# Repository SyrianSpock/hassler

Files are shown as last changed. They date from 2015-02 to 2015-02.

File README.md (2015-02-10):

Portable Hassler circuit
========================

Portable version of the hassler circuit to get rid of office noise.

This project focuses on building a portable version of the Hassler circuit.
Inspired by the analog pioneer Bob Widlar and the work of Craig at [analog zoo](http://www.analogzoo.com/2015/01/building-the-widlar-hassler).

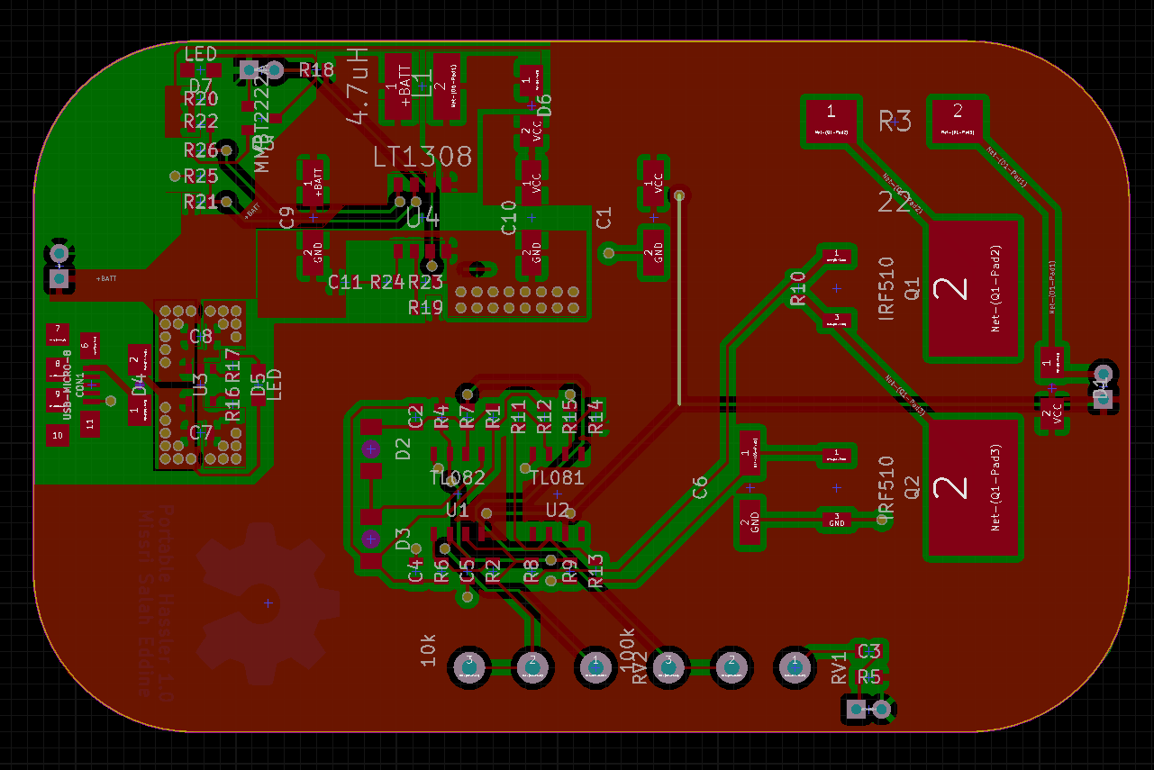
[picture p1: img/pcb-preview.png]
pcb


Features:
---------
* Emits a high frequency sound when there is noise
* Runs on one LiPo / Lithium-ion cell battery
* Micro USB rechargeable

License
-------
This project is released under the Creative Commons CC-BY-SA-4.0 license.
See http://creativecommons.org/licenses/by-sa/4.0/ for details.

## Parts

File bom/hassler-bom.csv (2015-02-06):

Reference | Value | Quantity | Kicad Footprint | URL
C1 | 220u | 1 | Capacitors_SMD:c_elec_6.3x7.7
C2 | 10p | 1 | SMD_Packages:SMD-0603
C3 | 1u | 1 | SMD_Packages:SMD-0603
C4 | 10u | 1 | SMD_Packages:SMD-0603
C5 | 680p | 1 | SMD_Packages:SMD-0603
C6 C9 C10 | 47u | 3 | Capacitors_SMD:c_elec_6.3x7.7
C7 C8 | 4.7u | 2 | SMD_Packages:SMD-0603
C11 | 330p | 1 | SMD_Packages:SMD-0603
CON1 | USB-MICRO-B | 1 | _connectors:_Micro-USB-AB-receptacle-SMT
D1 | S1J-13-F | 1 | Diodes_SMD:Diode-SMA_Standard
D2 D3 | 1N4148W | 2 | Diodes_SMD:Diode-MiniMELF_Standard
D4 D6 | MBRA140 | 2 | Diodes_SMD:Diode-SMA_Standard
D5 D7 | LED | 2 | LEDs:LED-0805
J1 | JST | 1 | _connectors:_Pin2mm_2
L1 | 4.7uH | 1 | _standard:Inductor2300
MIC1 | MICROPHONE | 1 | _connectors:_Pin2mm_2
Q1 Q2 | IRF510 | 2 | _standard:TO-263
Q3 | MMBT2222A | 1 | SMD_Packages:SOT-23
R1 R10 | 10M | 2 | SMD_Packages:SMD-0603
R2 R6 R12 | 1M | 3 | SMD_Packages:SMD-0603
R3 | 22 | 1 | _standard:PowerRes_SM_3
R4 R9 R15 R18 | 10k | 4 | SMD_Packages:SMD-0603
R5 | 22k | 1 | SMD_Packages:SMD-0603
R7 R8 R26 | 1k | 3 | SMD_Packages:SMD-0603
R11 | 20M | 1 | SMD_Packages:SMD-0603
R13 R14 | 2.2k | 2 | SMD_Packages:SMD-0603
R16 | 2k | 1 | SMD_Packages:SMD-0603
R17 | 330 | 1 | SMD_Packages:SMD-0603
R19 | 720k | 1 | SMD_Packages:SMD-0603
R20 | 470 | 1 | SMD_Packages:SMD-0603
R21 | 1.5M | 1 | SMD_Packages:SMD-0603
R22 R23 R25 | 100k | 3 | SMD_Packages:SMD-0603
R24 | 47k | 1 | SMD_Packages:SMD-0603
RV1 | 100k | 1 | Potentiometers:Potentiometer_WirePads_largePads
RV2 | 10k | 1 | Potentiometers:Potentiometer_WirePads_largePads
SP1 | SPEAKER | 1 | _connectors:_Pin2mm_2
SW1 | Off Switcher | 1 | _connectors:_Pin2mm_2
U1 | TL082 | 1 | SMD_Packages:SOIC-8-N
U2 | TL081 | 1 | SMD_Packages:SOIC-8-N
U3 | MCP73831 | 1 | SMD_Packages:SOT-23-5
U4 | LT1308 | 1 | _standard:S8

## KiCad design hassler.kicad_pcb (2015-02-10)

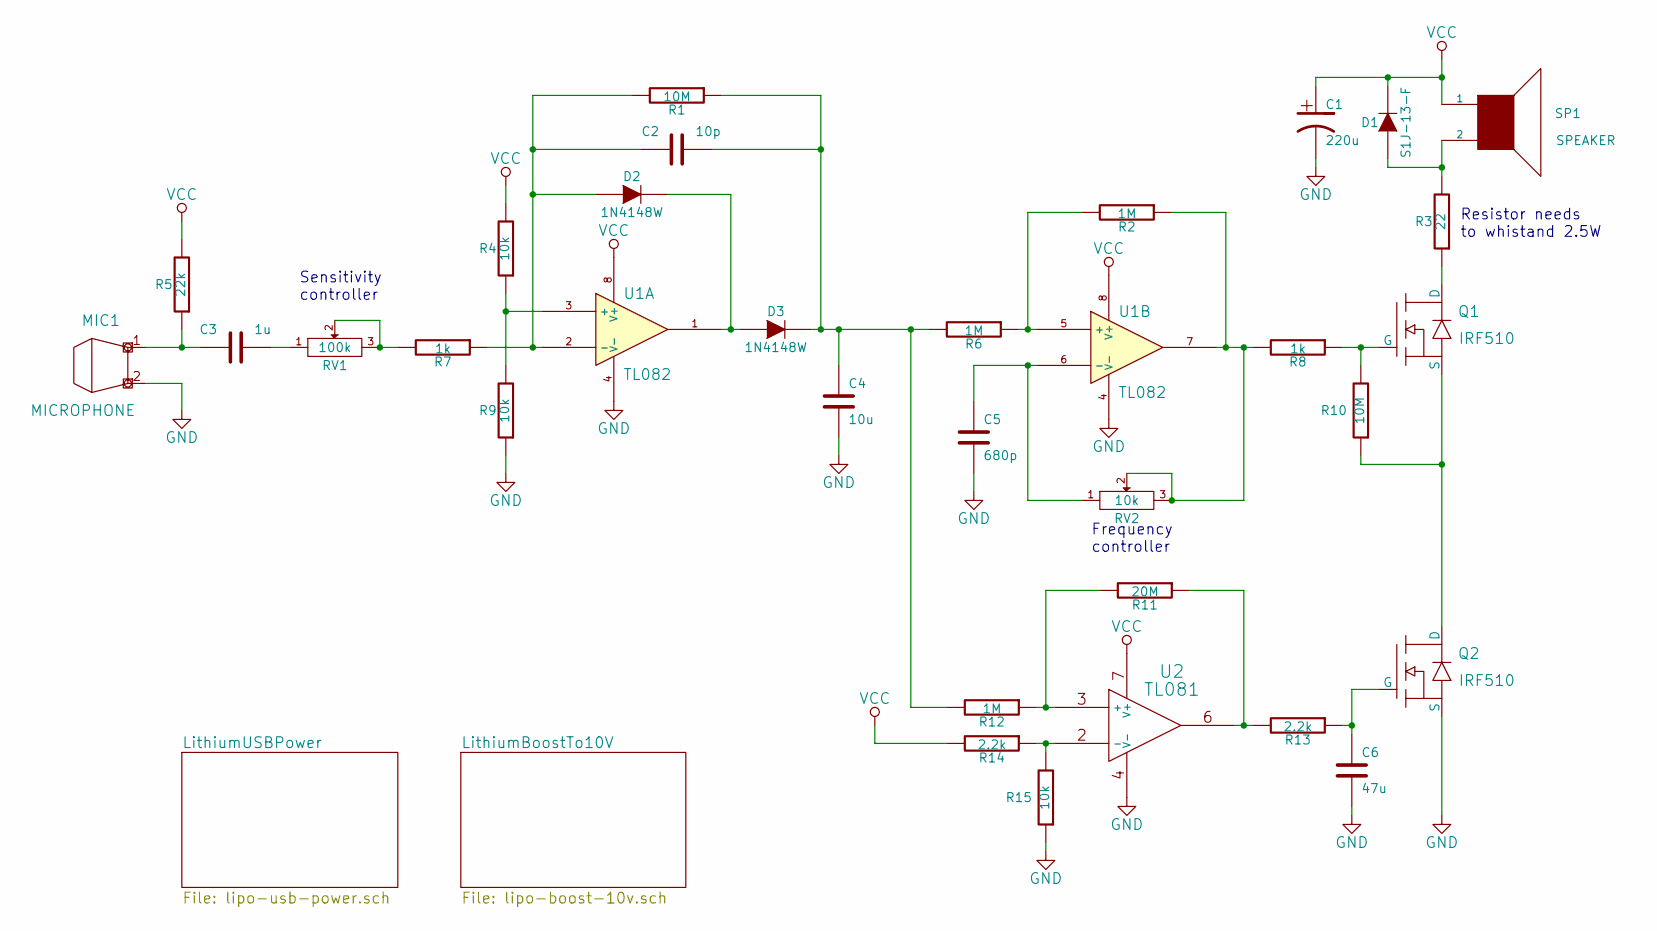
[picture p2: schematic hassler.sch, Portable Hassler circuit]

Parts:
C1: 220u
C2: 10p
C3: 1u
C4: 10u
C5: 680p
C6: 47u
D1: S1J-13-F
D2, D3: 1N4148W
MIC1: MICROPHONE
Q1, Q2: IRF510
R1, R10: 10M
R2, R6, R12: 1M
R3: 22
R4, R9, R15: 10k
R5: 22k
R7, R8: 1k
R11: 20M
R13, R14: 2.2k
RV1: 100k
RV2: 10k
SP1: SPEAKER
U1: TL082
U2: TL081

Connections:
GND: C1.2, C4.2, C5.2, C6.2, MIC1.2 (MIC-), Q2.3 (S), R9.1, R15.1, U1.4 (V-), U2.4 (V-); also elsewhere on the board
unnamed: C2.1, C4.1, D3.2 (K), R1.1, R6.2, R12.2
unnamed: C2.2, D2.1 (A), R1.2, R7.1, U1.2 (-)
unnamed: C3.1, MIC1.1 (MIC+), R5.1
unnamed: C3.2, RV1.1
unnamed: C5.1, RV2.1, U1.6 (-)
unnamed: C6.1, Q2.1 (G), R13.1
unnamed: D1.1 (A), R3.2, SP1.2
unnamed: D2.2 (K), D3.1 (A), U1.1
unnamed: Q1.1 (G), R8.1, R10.2
unnamed: Q1.2 (D), R3.1
unnamed: Q1.3 (S), Q2.2 (D), R10.1
unnamed: R2.1, R8.2, RV2.2, RV2.3, U1.7
unnamed: R2.2, R6.1, U1.5 (+)
unnamed: R4.1, R9.2, U1.3 (+)
unnamed: R7.2, RV1.2, RV1.3
unnamed: R11.1, R13.2, U2.6
unnamed: R11.2, R12.1, U2.3 (+)
unnamed: R14.1, R15.2, U2.2 (-)
VCC: C1.1, D1.2 (K), R4.2, R5.2, R14.2, SP1.1, U1.8 (V+), U2.7 (V+); also elsewhere on the board

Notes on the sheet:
Resistor needs to whistand 2.5W
Frequency controller
Sensitivity controller

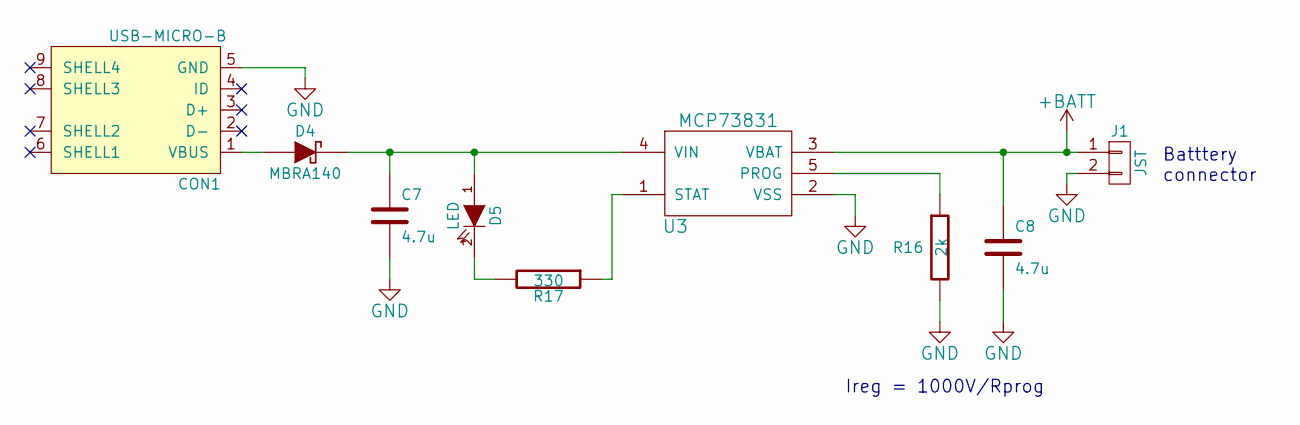
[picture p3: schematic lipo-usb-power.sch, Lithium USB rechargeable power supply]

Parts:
C7, C8: 4.7u
CON1: USB-MICRO-B
D4: MBRA140
D5: LED
J1: JST
R16: 2k
R17: 330
U3: MCP73831

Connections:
+BATT: C8.1, J1.1, U3.3 (VBAT); also elsewhere on the board
GND: C7.2, C8.2, CON1.5 (GND), J1.2, R16.2, U3.2 (VSS); also elsewhere on the board
unnamed: C7.1, D4.2 (K), D5.1 (A), U3.4 (VIN)
unnamed: CON1.1 (VBUS), D4.1 (A)
unnamed: D5.2 (K), R17.2
unnamed: R16.1, U3.5 (PROG)
unnamed: R17.1, U3.1 (STAT)

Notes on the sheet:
Ireg = 1000V/Rprog
Batttery connector

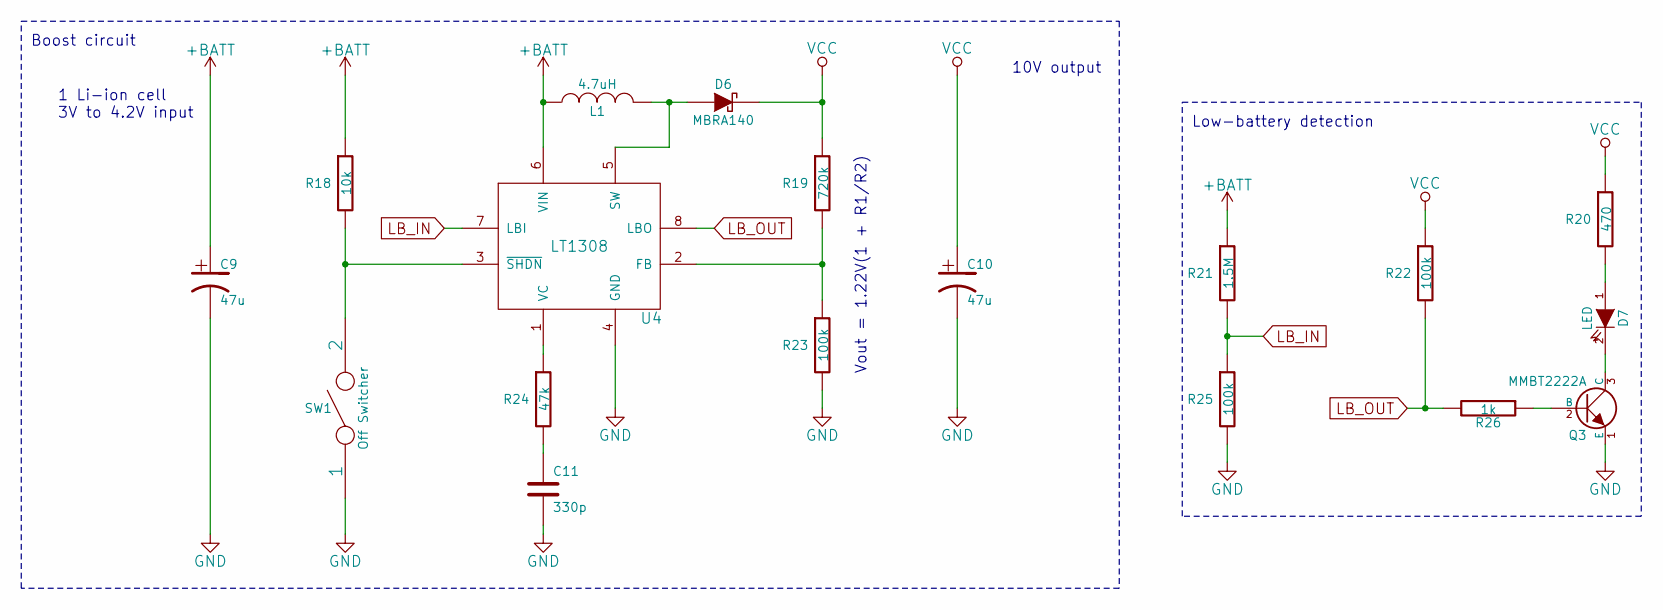
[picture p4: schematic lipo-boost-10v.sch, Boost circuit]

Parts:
C9, C10: 47u
C11: 330p
D6: MBRA140
D7: LED
L1: 4.7uH
Q3: MMBT2222A
R18: 10k
R19: 720k
R20: 470
R21: 1.5M
R22, R23, R25: 100k
R24: 47k
R26: 1k
SW1: Off Switcher
U4: LT1308

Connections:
+BATT: C9.1, L1.1, R18.1, R21.1, U4.6 (VIN); also elsewhere on the board
GND: C9.2, C10.2, C11.2, Q3.1 (E), R23.2, R25.2, SW1.1, U4.4 (GND); also elsewhere on the board
LB_IN: R21.2, R25.1, U4.7 (LBI)
LB_OUT: R22.2, R26.2, U4.8 (LBO)
unnamed: C11.1, R24.2
unnamed: D6.1 (A), L1.2, U4.5 (SW)
unnamed: D7.1 (A), R20.2
unnamed: D7.2 (K), Q3.3 (C)
unnamed: Q3.2 (B), R26.1
unnamed: R18.2, SW1.2, U4.3 (~SHDN)
unnamed: R19.2, R23.1, U4.2 (FB)
unnamed: R24.1, U4.1 (VC)
VCC: C10.1, D6.2 (K), R19.1, R20.1, R22.1; also elsewhere on the board

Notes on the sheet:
Vout = 1.22V(1 + R1/R2)
1 Li-ion cell 3V to 4.2V input
10V output
Low-battery detection
Boost circuit

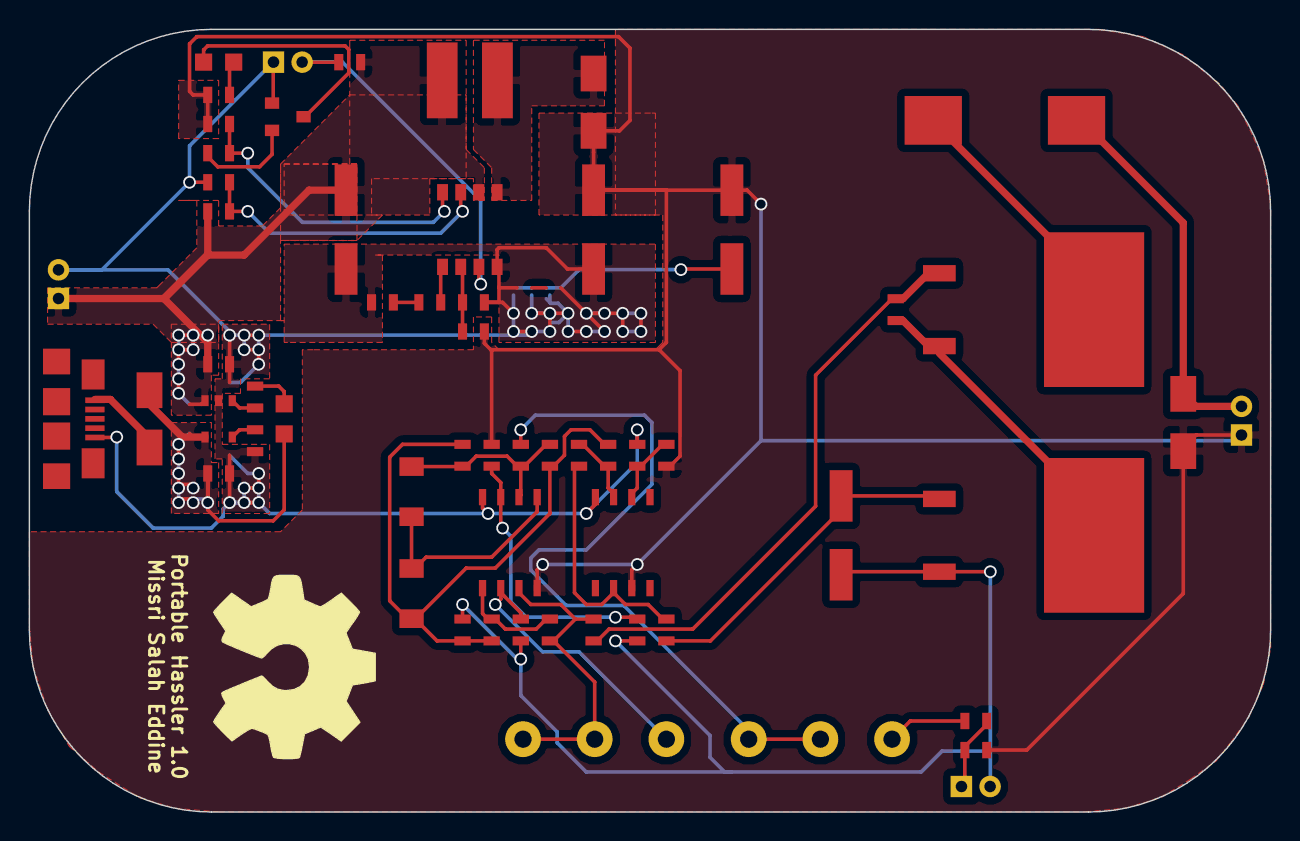
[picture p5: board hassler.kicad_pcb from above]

Board: 2 copper layers, 86.6 x 54.6 mm, 59 parts (0 on the bottom side), 36 nets.

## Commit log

2015-02-02 Add hassler circuit
    [hassler.sch]
2015-02-02 Add power supply circuit with Lithium battery and USB recharge
    [hassler.sch, lipo-usb-power.sch]
2015-02-03 Minor corrections to schematic
    [hassler.sch, lipo-boost-10v.sch, lipo-usb-power.sch]
2015-02-04 Add lithium cell to 10v boost circuit
    [lipo-boost-10v.sch, lipo-usb-power.sch]
2015-02-04 Add low-battery detection stage
    [hassler.sch, lipo-boost-10v.sch, lipo-usb-power.sch]
2015-02-04 Correct value of a resistor & Generate netlist
    [hassler.sch, lipo-boost-10v.sch, lipo-usb-power.sch]
2015-02-04 Associate footprints to components
    [hassler.sch, lipo-boost-10v.sch, lipo-usb-power.sch]
2015-02-05 Finish footprint association & Add components to pcb
    [hassler.kicad_pcb, hassler.sch, lipo-boost-10v.sch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]
2015-02-05 Layout lipo recharge circuit
    [hassler.kicad_pcb]
2015-02-06 Layout boost circuit
    [hassler.kicad_pcb]
2015-02-06 Finish PCB layout
    [hassler.kicad_pcb]
2015-02-06 Generate gerber files & Add bom
    [hassler-B_Cu.gbl, hassler-B_Mask.gbs, hassler-B_SilkS.gbo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]
2015-02-10 Add license and OSH logo
    [hassler-B_Cu.gbl, hassler-B_Mask.gbs, hassler-B_SilkS.gbo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]
